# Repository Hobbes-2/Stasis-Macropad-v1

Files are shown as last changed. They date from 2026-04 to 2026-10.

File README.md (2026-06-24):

Stasis Macropad (v1)

My first PCB, as well as first project for forge. (Originally planned to be submitted to Stasis, hence the name)

A basic macropad with:
6 keys,
A rotary encoder switch,
A OLED display

This project is meant both as a useful tool for me to use (i might try using it for things like tetris or such) and a perfect learning oppertunity. I have never done hardware hackathons/projects before, so this is a really good chance for me to learn. I originally used the hackclub macropad tutorial, and then deviated from it to get to what i have now. (https://hackpad.hackclub.com/guide) 
The keys are arranged in a matrix, and the display and rotary encoder are wired in seprately (from the matrix). The microcontroller im using ([XIAO-SEEEDUINO](https://wiki.seeedstudio.com/Seeeduino-XIAO/)) has USB-C connection for power. The firmware is written in python with KMK. 

3D render of the pcb


Schematics and layout



Case



All together


Keys


BOM
|Name |Purpose |Quantity|Total Cost (USD)|Link |Distributor |
|---|---|---|---|---|---|
|PCB |The actual pcb |1 |5.12 | |JLCPCB |
|3d Printed Case & Keys |The case and keys |1 |7 | |Printing Legion|
|Cherry MX Switch (MX1A-L1NN)|The keys of this macropad |6 |6 |https://www.mouser.com/ProductDetail/CHERRY/MX1A-L1NN?qs=F5EMLAvA7IDlALNAurZTXA%3D%3D|Mouser |
|0.91" OLED Graphic 128x32 |The display of this macropad; im going to try to make it log recent inputs|1 |3.9 |https://www.amazon.com/gp/product/B079BN2J8V/ref=ox_sc_act_title_1?smid=A1N6DLY3NQK2VM&psc=1|Amazon  |
|SEEEDUINO XIAO |The microcontroller of this macropad |1 |5.4 |https://www.digikey.com/en/products/detail/seeed-technology-co-ltd/102010328/11506471|Digikey |
|1N4148 |Preventing ghosting in the keyboard matrix |6 |0.83 |https://www.digikey.com/en/products/detail/smc-diode-solutions/1N4148W/6022450 |Digikey |
|EC11E15244G1 |Changing volume |1 |4.63 |https://www.digikey.com/en/products/detail/alps-alpine/EC11E15244G1/21721550 |Digikey |

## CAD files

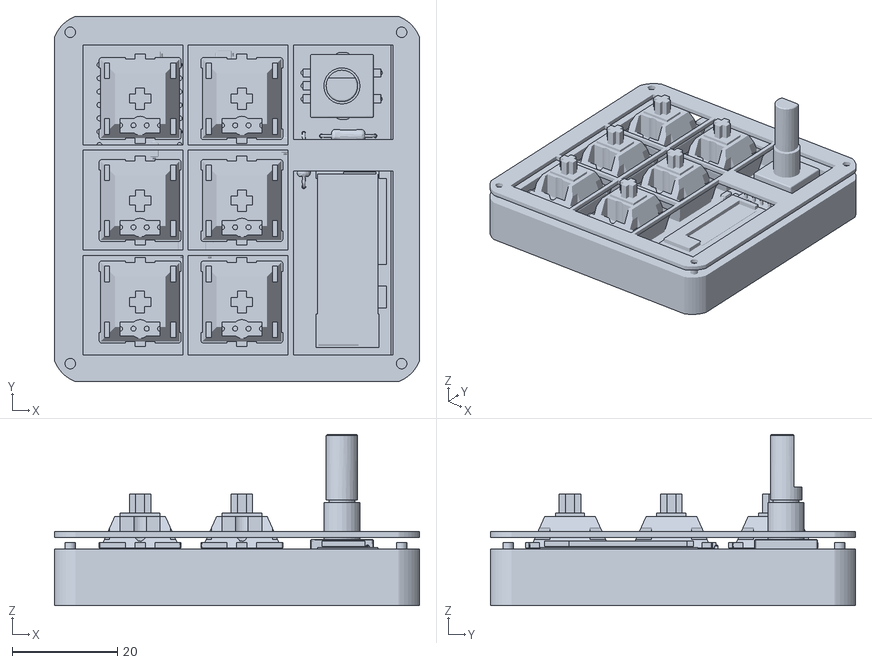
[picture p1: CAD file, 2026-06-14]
FullAssembly.stl
69.4 x 69.4 x 32.6

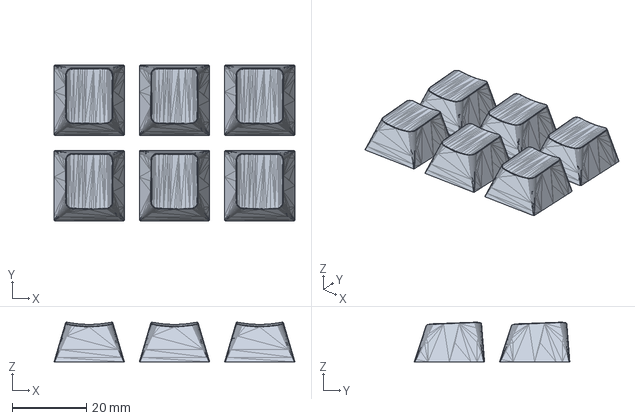
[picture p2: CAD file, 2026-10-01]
MacropadV1Keys.step
65.0 x 42.0 x 10.7 mm

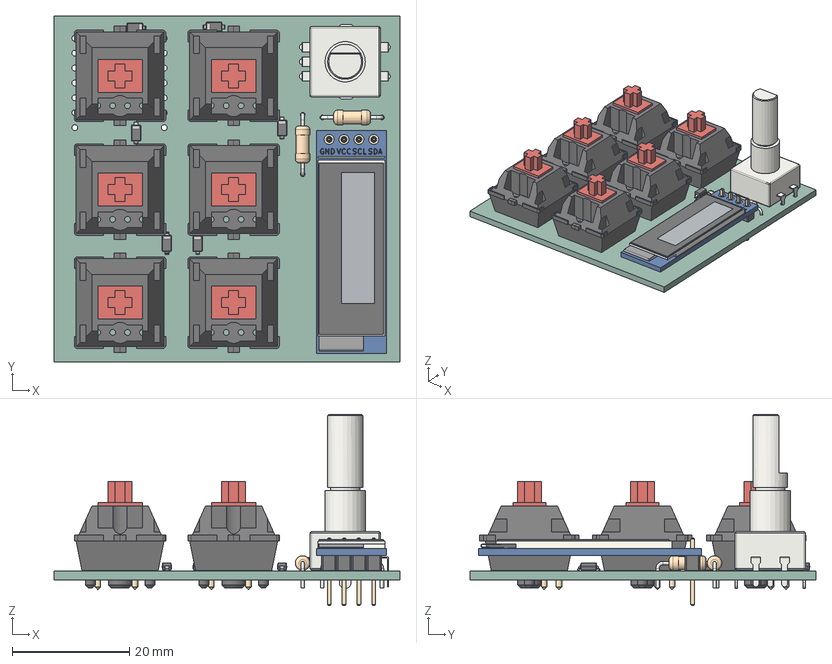
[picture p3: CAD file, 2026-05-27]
MacropadV1.step
59.0 x 59.0 x 32.6 mm
D_SOD-123 x 6
SDAText
SCLText
VCCText
GNDText
SilkscreenLine
Plating
ActiveArea-noText
Ribbon
Screen
Panel
PCB
SW_Cherry_MX_1.00u_PCB x 6
R_Axial_DIN0207_L6.3mm_D2.5mm_P10.16mm_Horizontal x 2
RotaryEncoder_Alps_EC11E-Switch_Vertical_H20mm
MacropadV1_PCB

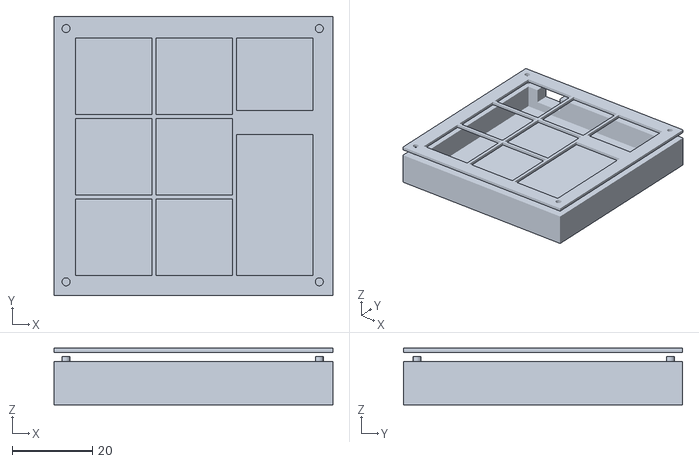
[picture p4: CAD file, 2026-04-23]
MacropadV1Case.stl
69.4 x 69.4 x 14.1

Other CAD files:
MacropadV1Keys.stl

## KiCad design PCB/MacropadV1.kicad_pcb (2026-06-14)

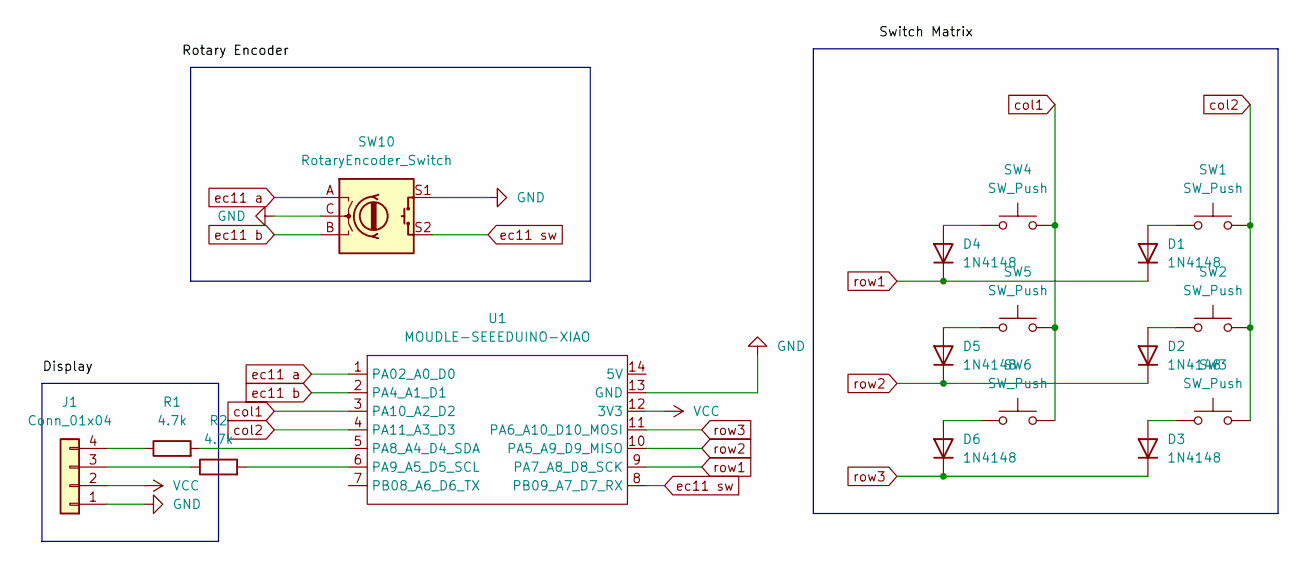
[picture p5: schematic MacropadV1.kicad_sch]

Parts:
D1, D2, D3, D4, D5, D6: 1N4148; D_SOD-123
J1: Conn_01x04; SSD1306-0.91-OLED-4pin-128x32
R1, R2: 4.7k; R_Axial_DIN0207_L6.3mm_D2.5mm_P10.16mm_Horizontal
SW1, SW2, SW3, SW4, SW5, SW6: SW_Push; SW_Cherry_MX_1.00u_PCB
SW10: RotaryEncoder_Switch; RotaryEncoder_Alps_EC11E-Switch_Vertical_H20mm
U1: MOUDLE-SEEEDUINO-XIAO; XIAO-Generic-Hybrid-14P-2.54-21X17.8MM

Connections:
GND: J1.1, SW10.C, SW10.S1, U1.13 (GND)
unnamed: D1.2 (A), SW1.1
unnamed: D2.2 (A), SW2.1
unnamed: D3.2 (A), SW3.1
unnamed: D4.2 (A), SW4.1
unnamed: D5.2 (A), SW5.1
unnamed: D6.2 (A), SW6.1
unnamed: J1.3, R2.1
unnamed: J1.4, R1.1
unnamed: R1.2, U1.5 (PA8_A4_D4_SDA)
unnamed: R2.2, U1.6 (PA9_A5_D5_SCL)
VCC: J1.2, U1.12 (3V3)
col1: SW4.2, SW5.2, SW6.2, U1.3 (PA10_A2_D2)
col2: SW1.2, SW2.2, SW3.2, U1.4 (PA11_A3_D3)
ec11 a: SW10.A, U1.1 (PA02_A0_D0)
ec11 b: SW10.B, U1.2 (PA4_A1_D1)
ec11 sw: SW10.S2, U1.8 (PB09_A7_D7_RX)
row1: D1.1 (K), D4.1 (K), U1.9 (PA7_A8_D8_SCK)
row2: D2.1 (K), D5.1 (K), U1.10 (PA5_A9_D9_MISO)
row3: D3.1 (K), D6.1 (K), U1.11 (PA6_A10_D10_MOSI)

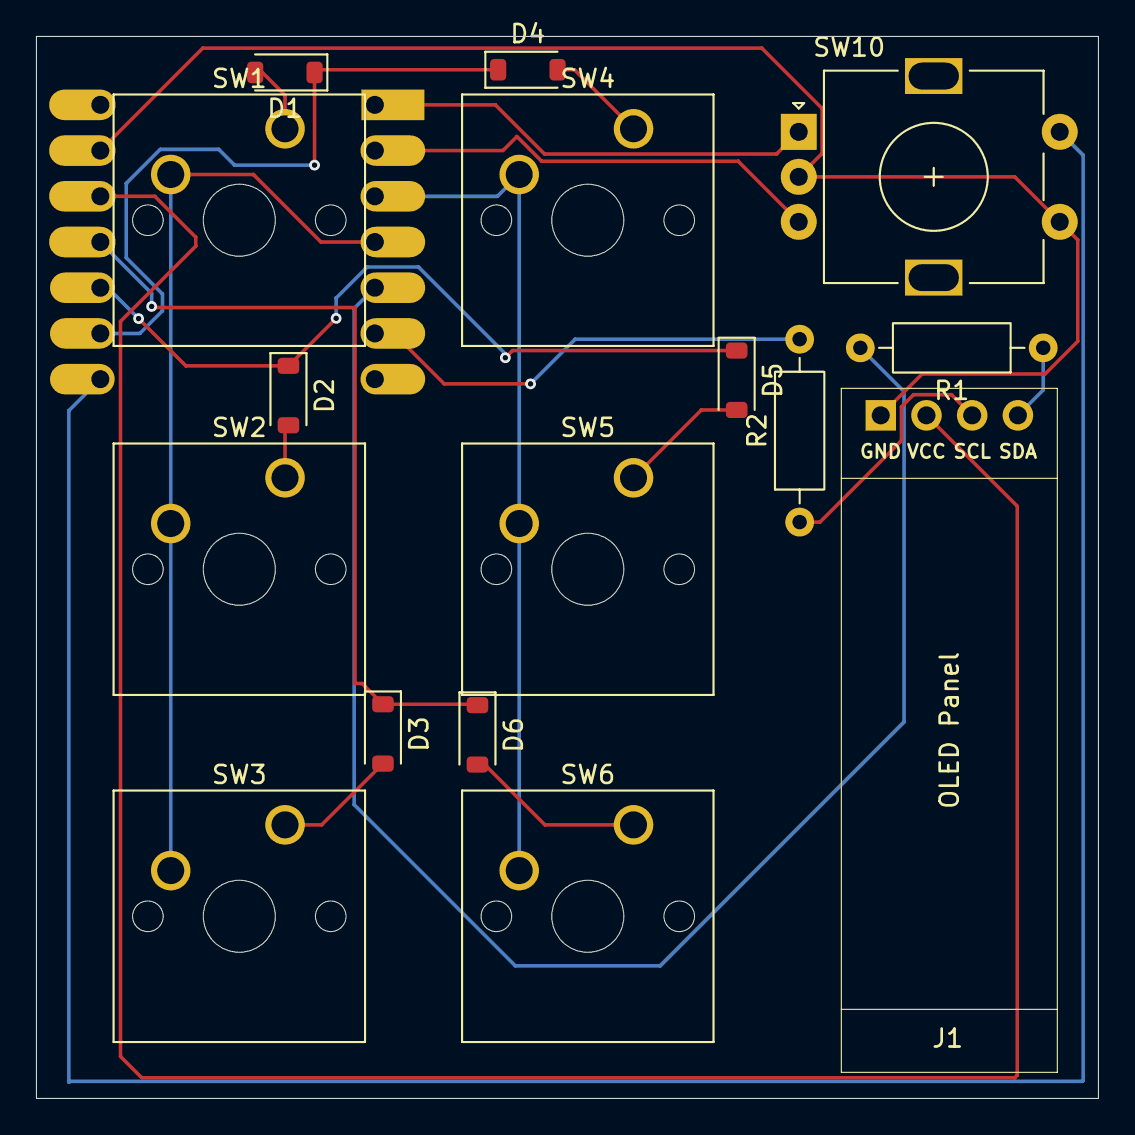
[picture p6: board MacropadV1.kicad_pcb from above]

Board: 2 copper layers, 59.0 x 59.0 mm, 17 parts (1 on the bottom side), 20 nets.

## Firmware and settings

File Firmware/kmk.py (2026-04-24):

import board
import busio

# Imports from the kmk library
from kmk.kmk_keyboard import KMKKeyboard
from kmk.scanners.keypad import KeysScanner
from kmk.keys import KC
from kmk.modules.macros import Press, Release, Tap, Macros
from kmk.modules.encoder import EncoderHandler

#For display
from kmk.extensions.display import Display, TextEntry, ImageEntry
from kmk.extensions.display.ssd1306 import SSD1306

#Main instance of the keyboard
keyboard = KMKKeyboard()

encoder_handler = EncoderHandler()

#Add the macro extension
macros = Macros()
keyboard.modules.append(macros)
keyboard.modules.append(encoder_handler)

#Pins for keys
PINS = [board.D4, board.D1, board.D5, board.D2, board.D6, board.D3]

#Encoder pins - regular direction encoder and a button
encoder_handler.pins = (board.GP17, board.GP15, board.GP14)


#Tell kmk we are not using a key matrix
keyboard.matrix = KeysScanner(
    pins=PINS,
    value_when_pressed=False,
)

zoom_in = KC.LCTL(KC.EQUAL)
zoom_out = KC.LCTL(KC.MINUS)

# Look here for keycodes: https://github.com/KMKfw/kmk_firmware/blob/main/docs/en/keycodes.md
# And here for macros: https://github.com/KMKfw/kmk_firmware/blob/main/docs/en/macros.md
keyboard.keymap = [
    [KC.LCTL(KC.X), KC.LCTL(KC.C), KC.LCTL(KC.V), KC.MACRO("Test"), KC.LCTL(KC.TAB), KC.LCTL(KC.LSFT(KC.TAB))],
    [KC.NO, KC.NO, KC.NO, KC.NO, KC.NO, KC.NO]
]

encoder_handler.map = [
    ((KC.VOLD, KC.VOLU, KC.MUTE),),
    ((zoom_in, zoom_out, KC.NO),)
]

#Display time
i2c_bus = busio.I2C(board.GP_SCL, board.GP_SDA)

driver = SSD1306(
    i2c = i2c_bus,
    device_address = 0x3C,
)

mainDisplay = Display(
    display = driver,
    width = 128,
    height = 32,
    powersave_off_time = 30
)

mainDisplay.entries = [
    ImageEntry(image = "FillerImage.jpg", x=0, y=0),
]

keyboard.extensions.append(mainDisplay)

#Start kmk
if __name__ == '__main__':
    keyboard.go()


# Im gonna work on this later, for now i just want a working script with the basic setup

# logged_keys = []
# max_keys = 20

# def logKeys(key_input, is_pressed):
#     print("Working...")
#     key_name = str(key_input)
#     logged_keys.append(key_name)
#     if len(logged_keys) > max_keys:
#         logged_keys.pop(0)
#     return key_input

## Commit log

2026-04-10 commiting for the first time
    [MacropadV1.csv, MacropadV1.kicad_pcb, MacropadV1.kicad_sch]
2026-04-23 added case 3d models and updated pcb
    [MacropadV1.csv, MacropadV1.kicad_pcb, MacropadV1.kicad_sch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]
2026-04-24 Update README.md to everything BUT the BOM
2026-04-25 just making sure i didnt forget anything
    [MacropadV1.kicad_pcb, MacropadV1.kicad_sch]
2026-04-26 added a silkscreen image and added gerber files
    [MacropadV1.kicad_pcb]
2026-04-26 making sure no files got left out
    [MacropadV1.csv, MacropadV1_bom.csv]
2026-04-26 Added BOM to README
2026-04-26 Screwed up the BOM, should be fixed now
2026-04-26 Updated CAD pictures in readme
2026-05-04 updated bom link
    [MacropadV1_bom.csv]
2026-05-18 updated case 3d model
    [MacropadV1.kicad_pcb]
2026-05-19 Update README.md with pcb render
2026-05-27 fixed schematic display error
    [MacropadV1.kicad_pcb, MacropadV1.kicad_sch, MacropadV1.step]
2026-05-28 Add full cad screenshot to README
2026-05-29 Fixed schematic image
2026-06-14 added bom file
    [Macropad-bom.csv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]
2026-06-14 added full 3d models
    [FullAssembly.stl]
2026-06-15 Fixed diode link on bom
2026-06-15 Fixed pricing on bom (im lowk stupidddd)
2026-06-24 updated pcb price on bom
    [Macropad-bom.csv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]
2026-06-24 Updated PCB price
2026-10-01 forgot to add key stl and step models
    [MacropadV1Keys.step, MacropadV1Keys.stl]
